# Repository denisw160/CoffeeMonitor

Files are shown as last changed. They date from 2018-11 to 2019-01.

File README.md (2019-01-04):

# CoffeeMonitor
**Retrofit the coffee**

_State: Beta_

This project is a showcase for an IoT application that digitizes our "old" / conventional coffee machine. With the help of basic sensors this project shall show how existing "hardware" can be transformed into the modern digital world.

A presentation about the CoffeeMonitor can be found [here][1] (under construction).

## Why this scenario?

The classic coffee pot is widely used and everyone does not know the problem: if you want to have a coffee, the pot is empty. How good it would be if you knew in advance how much coffee was still available before you went on your way.

## The idea

In order to determine how full the coffee pot is, there are different variants to determine this. A simple variant is to weigh the coffee pot. There are already a number of sensors that can be connected directly.
If you know the empty and full weight, you can easily estimate the degree of filling of the coffee pot.
In addition, I wanted to know how often the coffee pot was refilled. Since the coffee pot has to be removed from the weighing plate, I used a distance sensor that monitors the occupancy of the plate. With the sensor one can count the change of the allocation and/or refilling so. 
Now the data from the sensors must be processed and made available to the user. For this I use a Raspberry Pi 3, which connects the necessary software and hardware components. The sensors are connected to the GPIO ports. The status of the coffee pot is then published via a web application. 

## The solution

All sensors are connected to the GPIO ports. This looks like this, for example. 

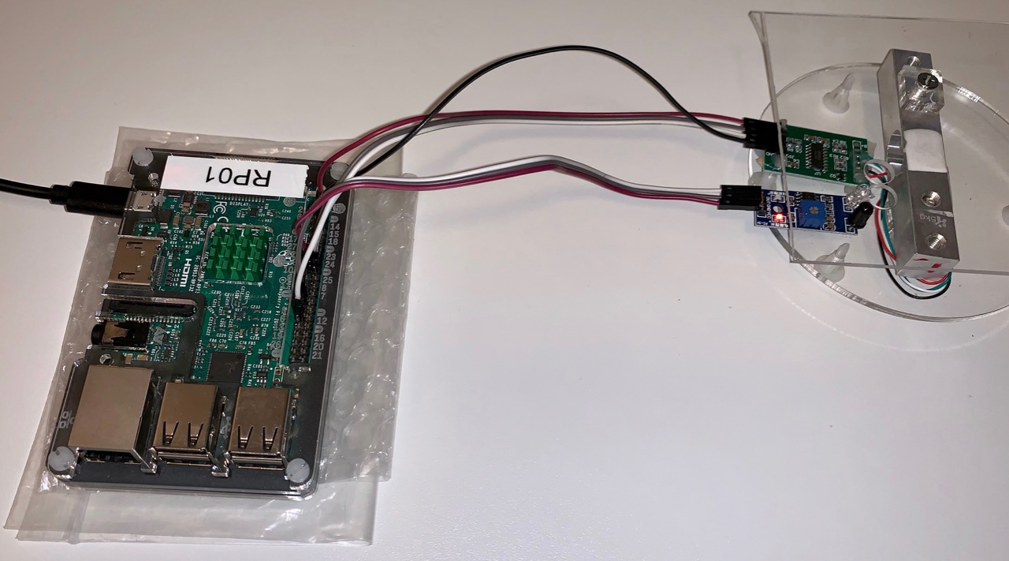
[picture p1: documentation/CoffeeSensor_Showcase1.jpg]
Raspberry complete


A weight cell with a HX711 is used as weighing sensor. In order for the IR distance sensor (FC-51) to work properly, the plate must be provided with two holes for weighing.

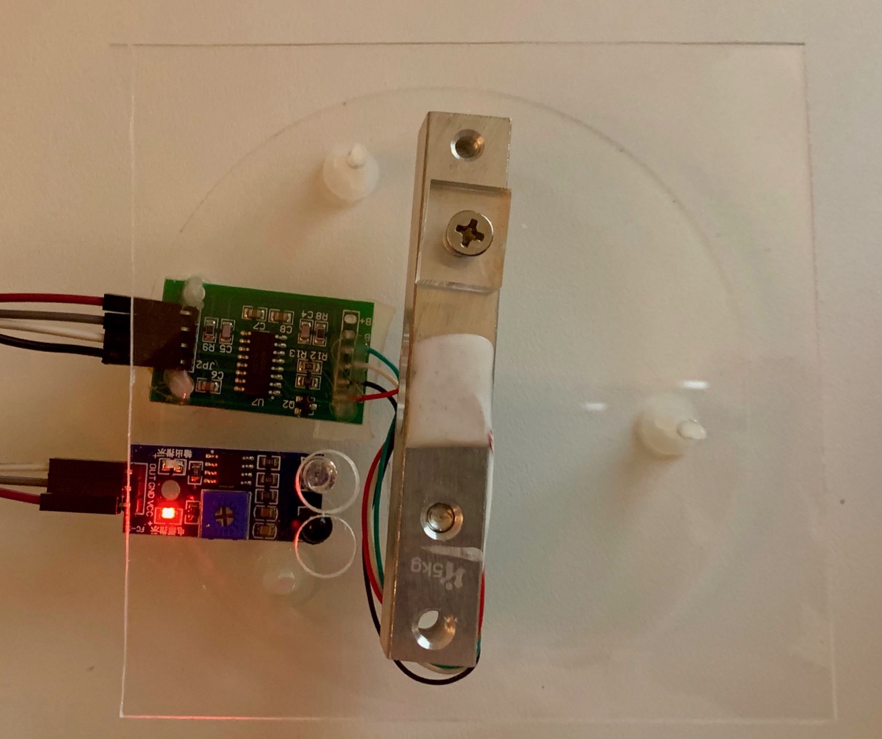
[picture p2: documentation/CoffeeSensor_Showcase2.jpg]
Sensors of the CoffeeMonitor


The structure and connection to the Raspberry Pi is as follows

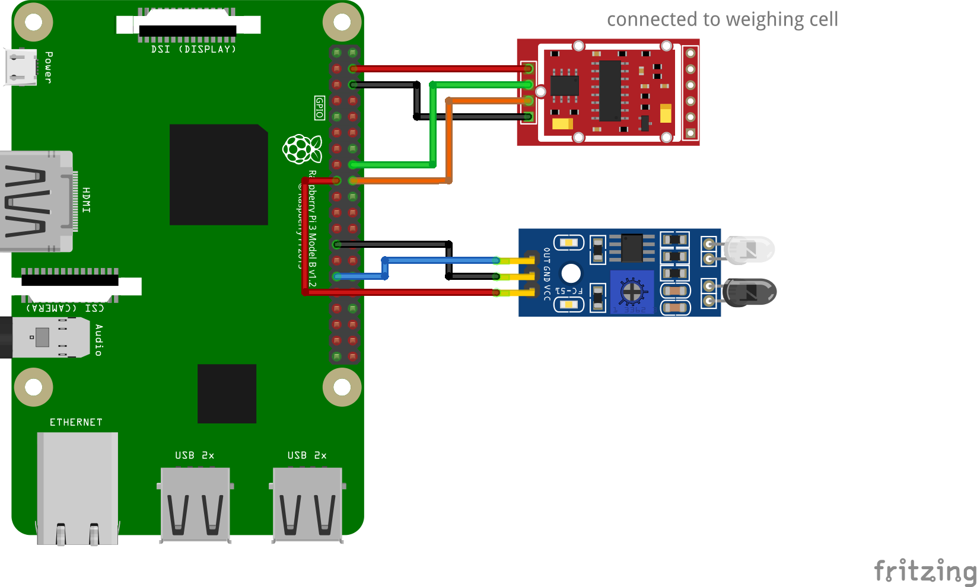
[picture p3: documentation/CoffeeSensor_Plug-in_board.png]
Plug-in board


The details of the electrical connection can be found in the [Fritzing file][2].

## The architecture

The software consists of three modules:
- [CoffeeSensor][3]: a Python script that reads the data from the sensors and transmits it to an MQTT broker.
- [CoffeeService][4]: a Spring Boot application (Java) that receives messages from the MQTT Broker and stores them in a MongoDB. The application also provides a REST API to retrieve the data from the MongoDB.
- [CoffeeApp][5]: An angular application that retrieves and displays the data via the REST service. 

Optional you can use a ESP8266 as CoffeeSensor. You found the source and the wiring diagram in [CoffeeSensor_ESP][6].

### The prerequisites

The following software components are required on the Raspberry:
- Mosquito MQTT-Broker
- MongoDB from 2.6
- Python 2.x and PIP
- Java 1.8
- Node.js

The installation can be carried out using the setup scripts.

## Features of the application

Display how full the coffee pot is

**Full**
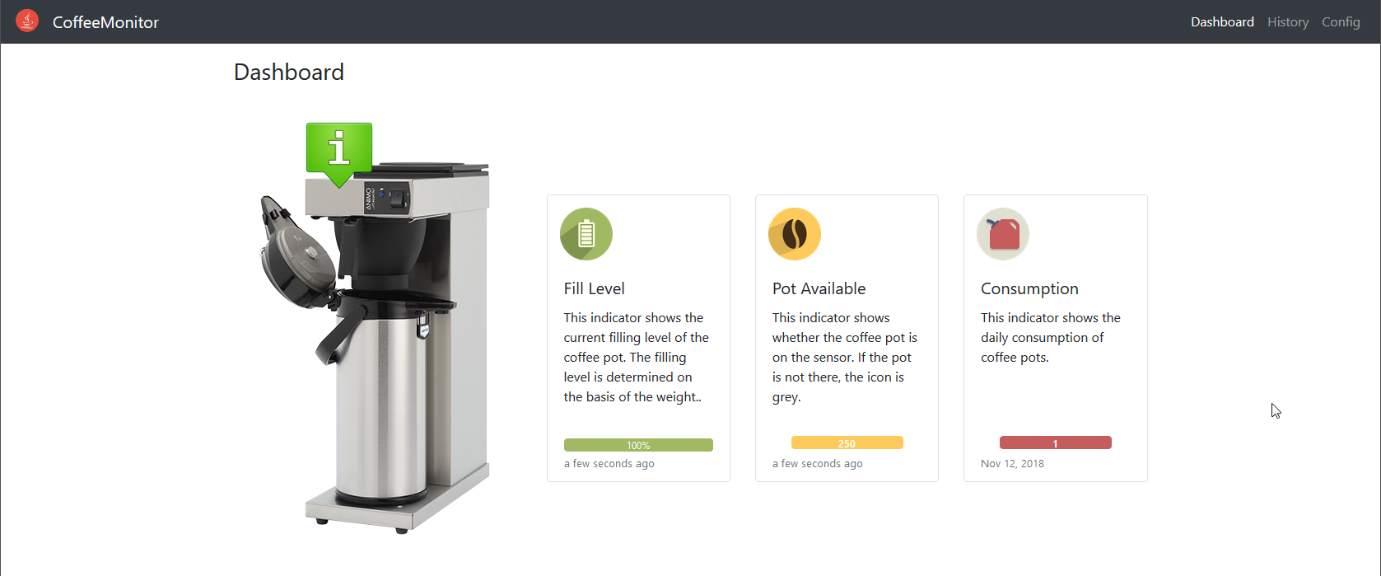
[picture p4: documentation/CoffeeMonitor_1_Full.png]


**Some coffee taken**
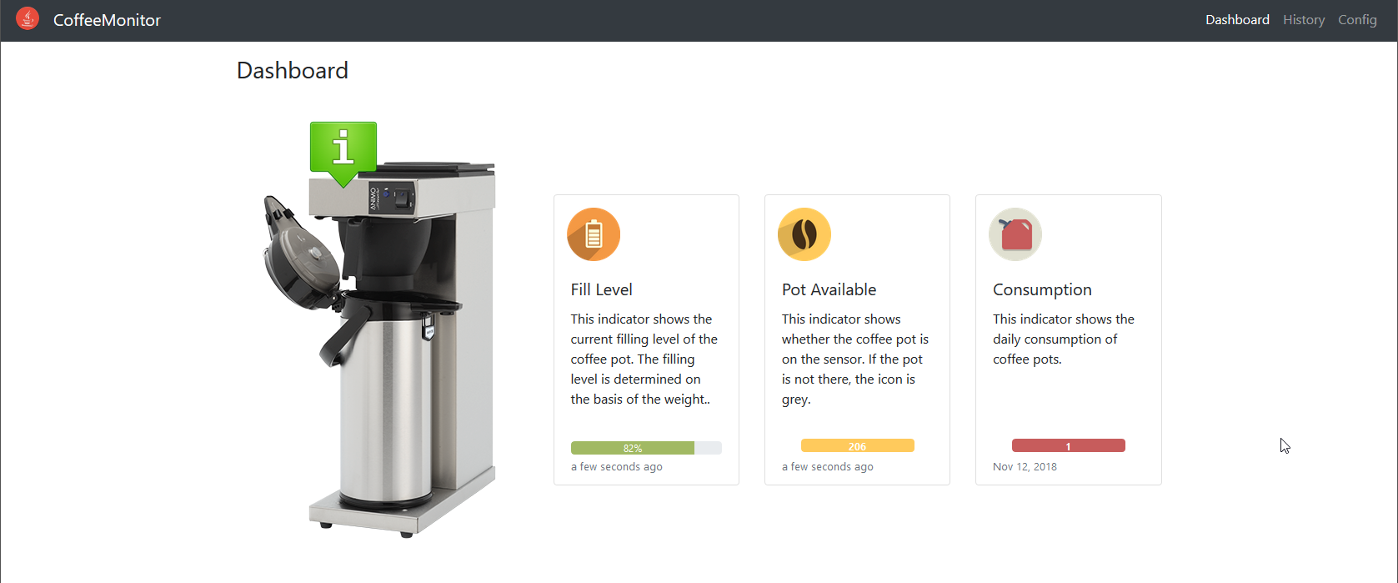
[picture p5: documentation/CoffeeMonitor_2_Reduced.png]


**Almost empty**
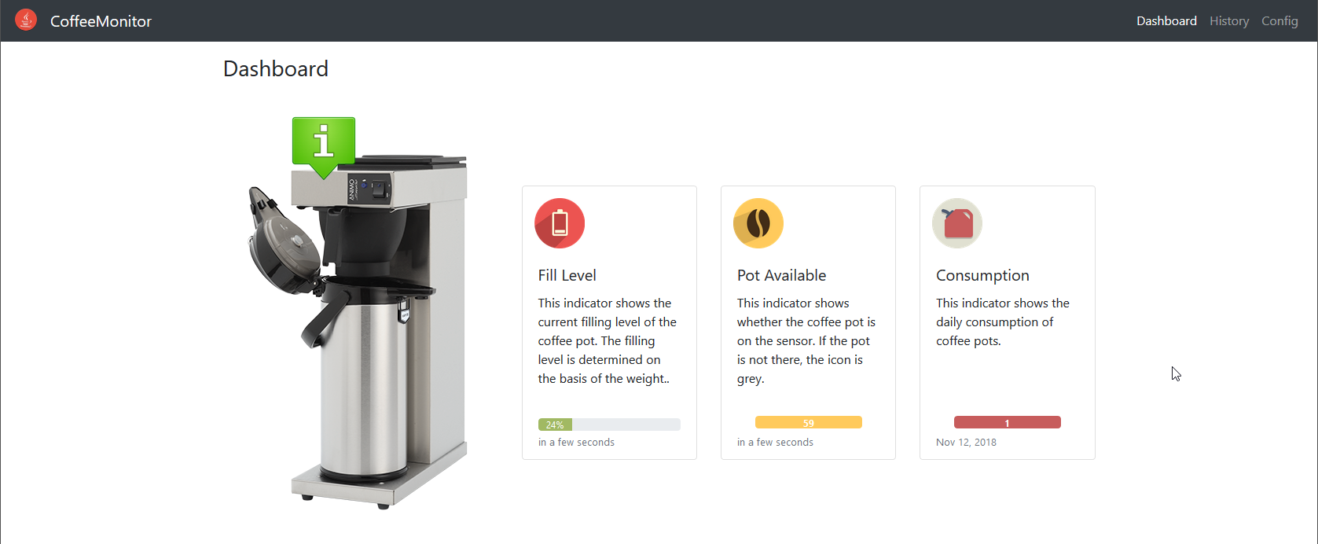
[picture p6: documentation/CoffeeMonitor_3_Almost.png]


**Empty**
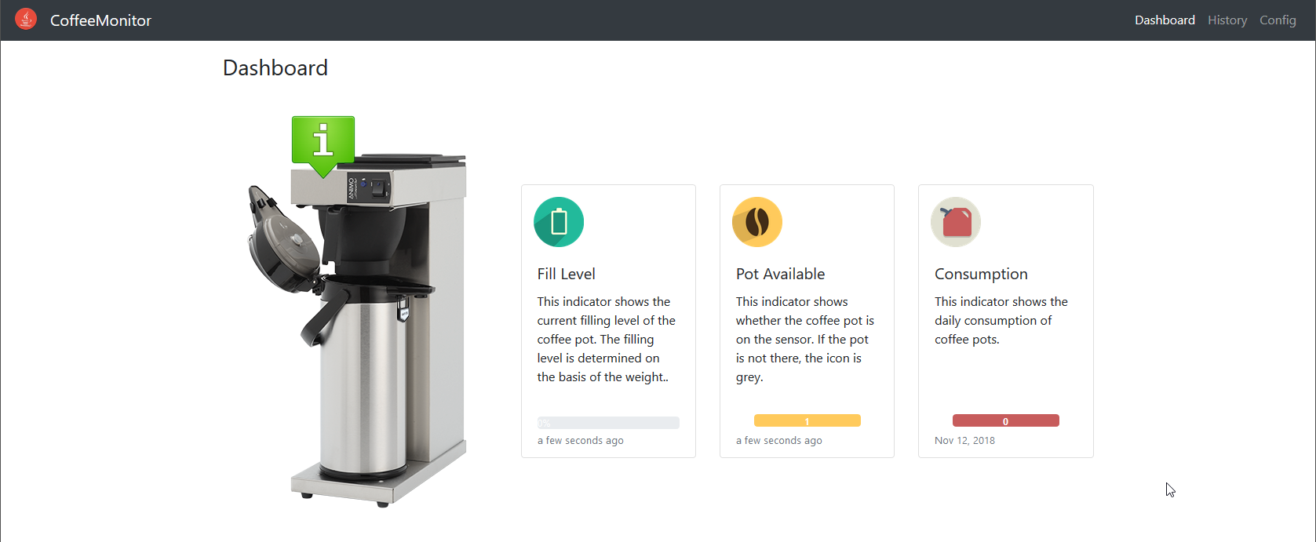
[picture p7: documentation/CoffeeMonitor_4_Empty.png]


If the application detects that no more data is being transferred, this is displayed.
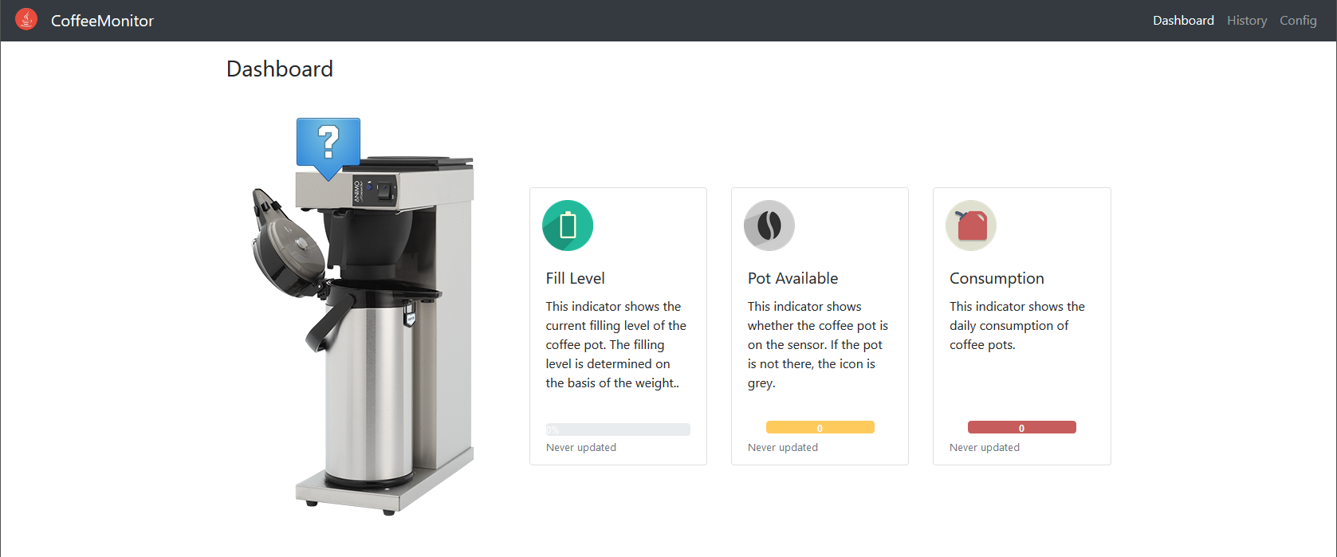
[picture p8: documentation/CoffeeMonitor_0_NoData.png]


The application can be used both on the desktop and on mobile devices.
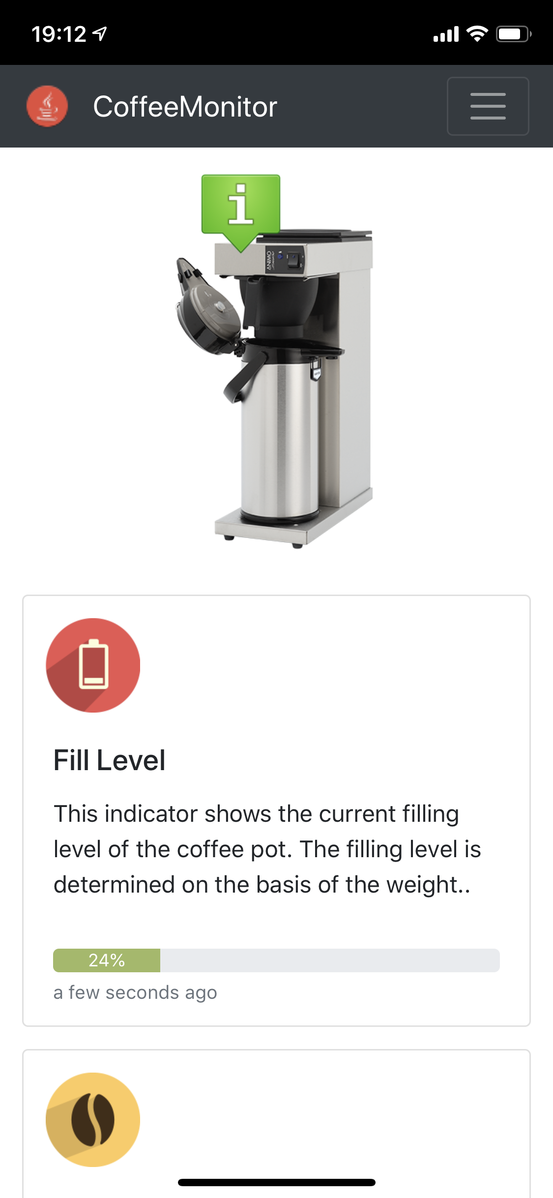
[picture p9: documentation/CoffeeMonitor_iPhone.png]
 <!-- .element height="50%" width="50%" -->

The configuration of the weights (filling and empty weight) can be set directly in the web application. 
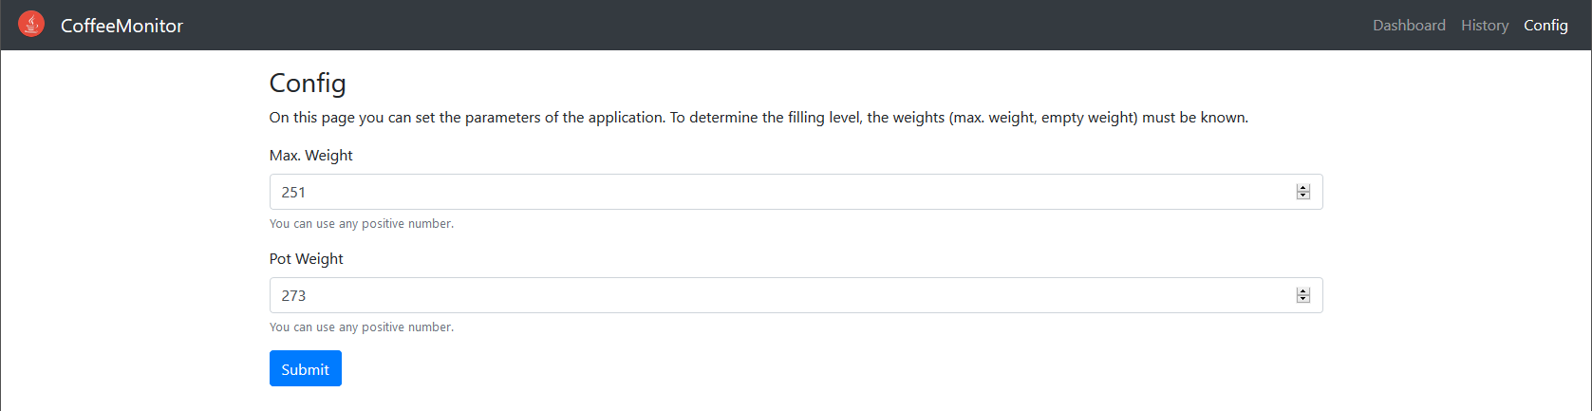
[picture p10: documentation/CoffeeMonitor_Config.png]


The progression of the filling level as well as the refilling can be tracked in the history.
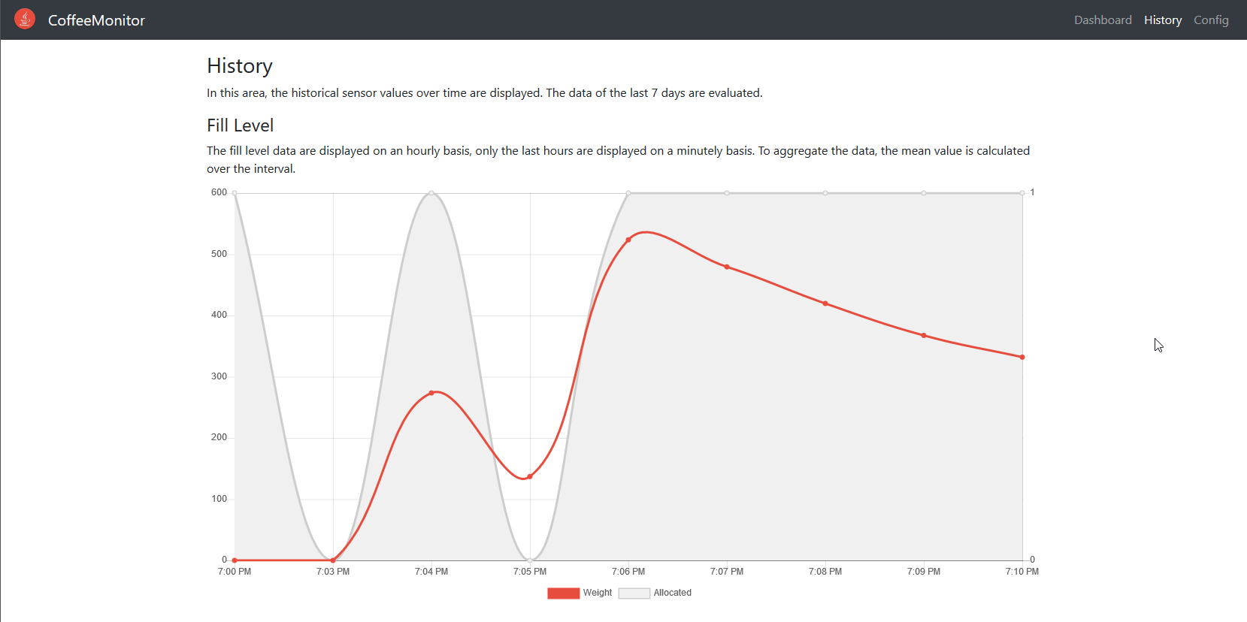
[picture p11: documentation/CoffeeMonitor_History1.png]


[1]:	documentation/CoffeeMonitor.pdf "Presentation of the CoffeeMonitor"
[2]:	documentation/CoffeeSensor.fzz
[3]:	coffeesensor
[4]:	coffeeservice
[5]:	coffeeapp
[5]:	coffeesensor_esp

[image-1]:	documentation/CoffeeSensor_Showcase1.jpg "Showcase 1"
[image-2]:	documentation/CoffeeSensor_Showcase2.jpg "Sensors"
[image-3]:	documentation/CoffeeSensor_Plug-in_board.png "Plug-in board"
[image-4]:	documentation/CoffeeMonitor_1_Full.png
[image-5]:	documentation/CoffeeMonitor_2_Reduced.png
[image-6]:	documentation/CoffeeMonitor_3_Almost.png
[image-7]:	documentation/CoffeeMonitor_4_Empty.png
[image-8]:	documentation/CoffeeMonitor_0_NoData.png
[image-9]:	documentation/CoffeeMonitor_iPhone.png
[image-10]:	documentation/CoffeeMonitor_Config.png
[image-11]:	documentation/CoffeeMonitor_History1.png

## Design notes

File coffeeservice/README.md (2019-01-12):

## CoffeeService

### Description
This module provides the backend for the system. The Spring Boot application handles the incoming mqtt messages from the
sensor and stores the data in a MongoDB. With rest services the data can be query from the clients. 
This module is written in Java 1.8. For Spring Boot the version 2.1.0.RELEASE is used.

### Scripts
To install the required components, simply run the setup script. The installation requires SUDO rights.

    bash>setup.sh

To install the service, simply run the install script. The installation requires SUDO rights.

    bash>install.sh

To uninstall the service, simply run the uninstall script. The installation requires SUDO rights.

    bash>uninstall.sh

The start script can be used to start the server on the local console.

    bash>start.sh

The run script can be used to build and start the server on the local console.

    bash>run.sh

For clean and building the service the following scripts can be used.

    bash>clean.sh
    bash>build.sh

To start the Docker build, execute this script

    bash>docker_build.sh

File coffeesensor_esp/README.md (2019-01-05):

## CoffeeSensor for ESP8266

### Description
This module can be installed on a ESP8266 / NodeMCU. It starts the monitoring of the sensors (GPIO) and transmits the values to the MQTT broker. 
This module is written in the Arduino IDE.

The data is send every 15 seconds. If you want another update interval, please change the variable INTERVAL.

The connection of the hardware (sensors) can be found [here][1].
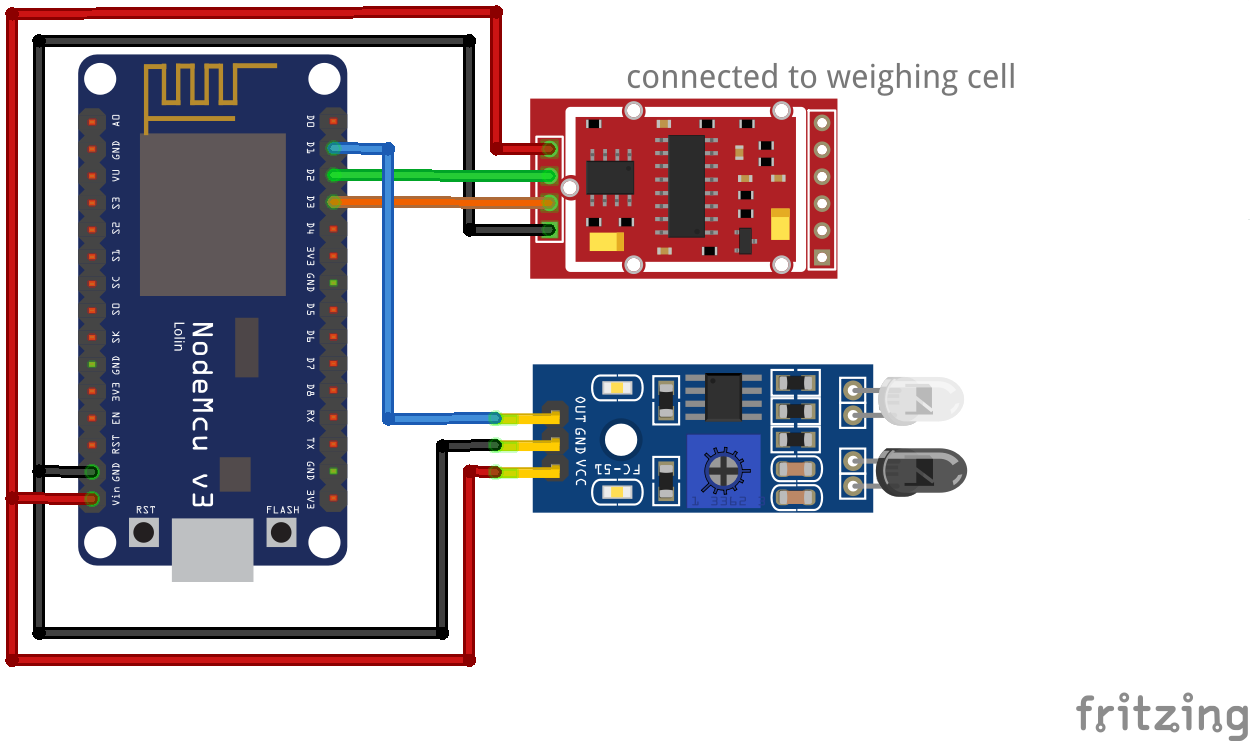
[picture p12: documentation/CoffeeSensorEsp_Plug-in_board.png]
Plug-in board for ESP8266


You need the following libraries in your Arduino IDE.

- HX711\_ADC by Olav Kallhovd ([https://github.com/olkal/HX711\_ADC][2])
- ArduinoMqtt by Oleg Kovalenko ([https://github.com/monstrenyatko/ArduinoMqtt][3])
- WiFiManager by tzapu ([https://github.com/tzapu/WiFiManager][4])

### Install
For install the software, open the file CoffeeSensorEsp.ino in your Arduino IDE and flash the ESP8266.

### Setup
On the first start of the NodeMCU it try to connect to a WiFi. If no WiFi parameter set, the NodeMCU stops and create and open WiFi network (AutoConnectAP). 
Please connect to this network and update your WiFi credentials and MQTT server. Then the NodeMCU restarts and automatically connect to your WiFi network.

You can canfigure the following MQTT parameter:

- MQTT Server: IP or hostname of your MQTT server
- MQTT Port: Your port of your server (default: 1883 or SSL: 8883)
- MQTT Topic: The topic for the sensor data, you must have write access for this topic
- MQTT User: Your username for the the server
- MQTT Password: The password for the user
- MQTT SSL: 1 for use SSL for the connection, 0 disable SSL

The MQTT ID of the client is the hostname of the ESP8266.

### Debug
In the serial monitor you can see the messages of the module.

[1]:	../documentation/CoffeeSensorEsp.fzz
[2]:	https://github.com/olkal/HX711_ADC "GitHub for HX711"
[3]:    https://github.com/monstrenyatko/ArduinoMqtt "GitHub for ArdunioMqtt"
[4]:    https://github.com/tzapu/WiFiManager "GitHub for WiFiManager"

[image-1]:	../documentation/CoffeeSensorEsp_Plug-in_board.png "Plug-in board for ESP8266"

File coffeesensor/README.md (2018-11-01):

## CoffeeSensor

### Description
This module starts the monitoring of the sensors (GPIO) and transmits the values to the MQTT broker. 
This module is written in Python 2.x. For the connection to the mqtt broker the python lib from paho.mqtt is used.

The connection of the hardware (sensors) can be found in the main folder under /documentation.

### Scripts
To install the required components, simply run the setup script. The installation requires SUDO rights.

    bash>setup.sh

To install the service, simply run the install script. The installation requires SUDO rights.

    bash>install.sh

To uninstall the service, simply run the uninstall script. The installation requires SUDO rights.

    bash>uninstall.sh

The start script can be used to start the server on the local console.

    bash>start.sh

The test script can be used for testing without hardware. It generates random values and transfers them.

    bash>test.sh

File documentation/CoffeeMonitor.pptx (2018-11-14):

## CoffeeMonitor

“Retrofit the coffee"

## The challenge

## The solution

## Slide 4

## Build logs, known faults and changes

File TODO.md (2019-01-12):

## Tasks and open points

- Design of the scale casing for determining the weight of the coffee pot (protected against moisture and excessive weights / pressure on the coffee pot)
- Add reset button for ESP8266
- Add JWT for securing the connection and active CSRF for POST requests
- Implement cleanup job for old data

## Ideas and next steps

- Native app for iOS and Android
- Indication when the coffee pot was last refilled
- Add RFID or NFC scanner for identify the coffee users / display the last users
- Adding Machine Learning (ML) for detection of invalid sensor data

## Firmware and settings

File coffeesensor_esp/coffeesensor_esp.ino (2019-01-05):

// External libraries
#include <FS.h> // this needs to be first, or it all crashes and burns...
#include <ESP8266WiFi.h>
#include <DNSServer.h>
#include <WiFiManager.h>
#include <ESP8266WebServer.h>
#include <HX711_ADC.h>
#include <MqttClient.h>
#include <ArduinoJson.h>

// Interval for update
#define INTERVAL 15000

// Show debug messages in serial
#define DEBUG true

// Port on NodeMCU (D1) for the allocation sensor
#define ALLOCATION_SENSOR D1

// Ports on NodeMCU for the weight sensor - SCK (D2) + DT (D3)
#define WEIGHT_SCK D2
#define WEIGHT_DT D3


// Control Parameter
// define your default values here, if there are different values in config.json, they are overwritten.
char mqttServer[50];
char mqttPort[6] = "1883";
char mqttTopic[50] = "me/wirries/coffeesensor";
char mqttSsl[2] = "0";
char mqttUsername[50];
char mqttPassword[50];


// HX711 - constructor (dout pin, sck pin):
HX711_ADC LoadCell(WEIGHT_DT, WEIGHT_SCK);

// MqttClient
MqttClient *mqtt = NULL;
WiFiClient network;
WiFiClientSecure netsecure;
String mqttId;
int mPort;
bool mSsl;
bool mSecure;

// Heartbeat status
boolean led = false;

// Time mills for update
long t;

// Flag for saving data
bool shouldSaveConfig = false;


//
// MqttSystem implementation
class MqttSystem: public MqttClient::System {
  public:

    unsigned long millis() const {
      return ::millis();
    }

    void yield(void) {
      ::yield();
    }
};


//
// Initialize and setup
void setup() {
  // Initialize Debug-Console
  Serial.begin(115200);
  Serial.println("Booting ...");


  // Initialize the pins as in-/output
  Serial.println("Initialize pins ...");
  pinMode(LED_BUILTIN, OUTPUT);
  pinMode(ALLOCATION_SENSOR, INPUT);


  // Handle configuration
  // Clean filesystem - remove old config
  //SPIFFS.format();

  // Read configuration from FS json
  Serial.println("Mounting file system ...");
  if (SPIFFS.begin()) {
    if (SPIFFS.exists("/config.json")) {
      // File exists, reading and loading
      Serial.println("Loading config from file ...");
      File configFile = SPIFFS.open("/config.json", "r");
      if (configFile) {
        size_t size = configFile.size();
        std::unique_ptr<char[]> buf(new char[size]);
        configFile.readBytes(buf.get(), size);
        DynamicJsonBuffer jsonBuffer;
        JsonObject& json = jsonBuffer.parseObject(buf.get());

        if (DEBUG) json.printTo(Serial);
        if (json.success()) {
          if (DEBUG) Serial.println("\nConfig parsed");

          strcpy(mqttServer, json["mqtt_server"]);
          strcpy(mqttPort, json["mqtt_port"]);
          strcpy(mqttTopic, json["mqtt_topic"]);
          strcpy(mqttSsl, json["mqtt_ssl"]);
          strcpy(mqttUsername, json["mqtt_username"]);
          strcpy(mqttPassword, json["mqtt_password"]);

          Serial.println("Config loaded");
        } else {
          Serial.println("Failed to load config");
        }
        configFile.close();
      }
    }
  } else {
    Serial.println("Failed to mount file system");
  }

  // The extra parameters to be configured (can be either global or just in the setup)
  // After connecting, parameter.getValue() will get you the configured value
  // id/name placeholder/prompt default length
  WiFiManagerParameter customMqttServer("server", "mqtt server", mqttServer, 50);
  WiFiManagerParameter customMqttPort("port", "mqtt port [int]", mqttPort, 6);
  WiFiManagerParameter customMqttTopic("topic", "mqtt topic", mqttTopic, 50);
  WiFiManagerParameter customMqttSsl("ssl", "mqtt ssl - 0 or 1", mqttSsl, 2);
  WiFiManagerParameter customMqttUsername("username", "mqtt username - blank for disable", mqttUsername, 50);
  WiFiManagerParameter customMqttPassword("password", "mqtt password - blank for disable", mqttPassword, 50);

  // WiFiManager - local intialization.
  WiFiManager wifiManager;
  // reset saved settings - for deleting the settings
  //wifiManager.resetSettings();

  // set config save notify callback
  wifiManager.setSaveConfigCallback(saveConfigCallback);

  // add all parameters
  wifiManager.addParameter(&customMqttServer);
  wifiManager.addParameter(&customMqttPort);
  wifiManager.addParameter(&customMqttTopic);
  wifiManager.addParameter(&customMqttSsl);
  wifiManager.addParameter(&customMqttUsername);
  wifiManager.addParameter(&customMqttPassword);

  // fetches ssid and pass from eeprom and tries to connect
  // if it does not connect it starts an access point
  // and goes into a blocking loop awaiting configuration
  wifiManager.autoConnect("AutoConnectAP");

  Serial.print("Connecting to WiFi .");
  while (WiFi.status() != WL_CONNECTED) {
    delay(500);
    Serial.print(".");
  }
  Serial.println(" connected!");
  Serial.println("Hostname: " + WiFi.hostname());
  Serial.println("IP: " + WiFi.localIP().toString());

  // Setup hostname as MQTT_ID
  mqttId = "CoffeeSensor_" + WiFi.hostname();

  // Setup / update parameter
  strcpy(mqttServer, customMqttServer.getValue());
  strcpy(mqttPort, customMqttPort.getValue());
  strcpy(mqttTopic, customMqttTopic.getValue());
  strcpy(mqttSsl, customMqttSsl.getValue());
  strcpy(mqttUsername, customMqttUsername.getValue());
  strcpy(mqttPassword, customMqttPassword.getValue());

  // Save the custom parameters to file system
  if (shouldSaveConfig) {
    Serial.println("Saving config ...");
    DynamicJsonBuffer jsonBuffer;
    JsonObject& json = jsonBuffer.createObject();
    json["mqtt_server"] = mqttServer;
    json["mqtt_port"] = mqttPort;
    json["mqtt_topic"] = mqttTopic;
    json["mqtt_ssl"] = mqttSsl;
    json["mqtt_username"] = mqttUsername;
    json["mqtt_password"] = mqttPassword;

    File configFile = SPIFFS.open("/config.json", "w");
    if (!configFile) {
      Serial.println("Failed to open config file for writing");
    }

    if (DEBUG) json.printTo(Serial);
    json.printTo(configFile);
    configFile.close();
    Serial.println("\nConfig saved");
  }

  // Setup port
  mPort = String(mqttPort).toInt();
  mSsl = String(mqttSsl) == "1";
  mSecure = String(mqttUsername).length() > 0;


  // Initialize MqttClient
  Serial.println("Initialize MQTT client ...");
  MqttClient::System *mqttSystem = new MqttSystem();
  MqttClient::Logger *mqttLogger = new MqttClient::LoggerImpl<HardwareSerial>(Serial);
  MqttClient::Network *mqttNetwork = mSsl ?  new MqttClient::NetworkClientImpl<WiFiClient>(netsecure, *mqttSystem) : new MqttClient::NetworkClientImpl<WiFiClient>(network, *mqttSystem);
  MqttClient::Buffer *mqttSendBuffer = new MqttClient::ArrayBuffer<128>();
  MqttClient::Buffer *mqttRecvBuffer = new MqttClient::ArrayBuffer<128>();
  MqttClient::MessageHandlers *mqttMessageHandlers = new MqttClient::MessageHandlersImpl<2>();
  MqttClient::Options mqttOptions;
  mqttOptions.commandTimeoutMs = 10000;
  mqtt = new MqttClient(mqttOptions, *mqttLogger, *mqttSystem, *mqttNetwork, *mqttSendBuffer, *mqttRecvBuffer, *mqttMessageHandlers);
  Serial.println("MQTT client is ready");


  // Initialize weight sensor
  Serial.println("Initialize weight sensor ...");

  float calValue = 1;
  // calibration value
  // How to find this value
  // First you need a comparison object whose weight you know. E.g. a water bottle can be used well.
  // The weight should have an average value of the maximum of the load cell.
  // First you have to comment out the line with the reference value. Then start the program and follow
  // the outputs. Place the object. The displayed values can be positive or negative.
  // In this example, values around -402000 were displayed at 1kg (=1000g).
  // So this reference value is: -402000 / 1000 = -402.
  calValue = 385.92;

  LoadCell.begin();
  long stabilisingtime = 2000; // tare preciscion can be improved by adding a few seconds of stabilising time
  LoadCell.start(stabilisingtime);

  if (LoadCell.getTareTimeoutFlag()) {
    Serial.println("Tare timeout, check MCU>HX711 wiring and pin designations");
  } else {
    LoadCell.setCalFactor(calValue); // set calibration value (float)
    Serial.println("Weight sensor is ready");
  }

  Serial.println("Setup completed.");
}

//
// Run system loop
void loop() {
  // update() should be called at least as often as HX711 sample rate; >10Hz@10SPS, >80Hz@80SPS
  // use of delay in sketch will reduce effective sample rate (be carefull with use of delay() in the loop)
  LoadCell.update();

  // Update and send data in interval
  if (millis() > t + INTERVAL) {
    boolean allocation = readAllocation();
    float weight = readWeight();
    sendMqttMessage(allocation, weight);

    heartbeat();
    t = millis();
  }
}

//
// Read the allocation from the sensor and
// return the value as boolean.
// - TRUE=allocated
// - FALSE=free
boolean readAllocation() {
  boolean allocation = digitalRead(ALLOCATION_SENSOR) == 0;

  // Debug message
  if (DEBUG) {
    Serial.print("Allocation is: ");
    if (allocation) {
      Serial.println("allocated");
    } else {
      Serial.println("free");
    }
  }

  return allocation;
}

//
// Read the weight from the sensor and
// return the value.
float readWeight() {
  float weight = LoadCell.getData();

  // Debug message
  if (DEBUG) {
    Serial.print("Weight is: ");
    Serial.println(weight);
  }

  return weight;
}

//
// Convert the sensor values to a JSON message
// and send the message to the MQTT broker.
void sendMqttMessage(boolean allocation, float weight) {
  // Check connection status
  if (!mqtt->isConnected()) {
    if (mSsl) {
      netsecure.stop(); // Close connection if exists
      Serial.println("Reconnecting to MQTT server (secure) ...");
      netsecure.connect(mqttServer, mPort); // Re-establish TCP connection with MQTT broker (secure)
      if (!netsecure.connected()) {
        Serial.println("Can't establish the TCP connection");
      }
    } else {
      network.stop(); // Close connection if exists
      Serial.println("Reconnecting to MQTT server ...");
      network.connect(mqttServer, mPort); // Re-establish TCP connection with MQTT broker
      if (!network.connected()) {
        Serial.println("Can't establish the TCP connection");
      }
    }

    // Start new MQTT connection
    MqttClient::ConnectResult connectResult;
    {
      // Connect
      MQTTPacket_connectData options = MQTTPacket_connectData_initializer;
      options.MQTTVersion = 4;
      if (mSecure) {
        Serial.println("Using login for mqtt  ...");
        options.username.cstring = (char*)mqttUsername;
        options.password.cstring = (char*)mqttPassword;
      }
      options.clientID.cstring = (char*)mqttId.c_str();
      options.cleansession = true;
      options.keepAliveInterval = 45; // 45 seconds
      MqttClient::Error::type rc = mqtt->connect(options, connectResult);
      if (rc != MqttClient::Error::SUCCESS) {
        Serial.print("Connection error: ");
        Serial.println(rc);
        return;
      }
    }
  } else {
    {
      // Sending MQTT message
      // Original structure: {"timestamp": "2019-01-04T10:54:49.517000", "allocated": true, "weight": 1.0406128215270019}
      // ESP8266 short structure : {"allocated": true, "weight": 1.0406128215270019}
      // timestamp will added by the service
      const String a = allocation ? "true" : "false";
      const String w = String(weight);
      const String m = "{\"allocated\": " + a + ", \"weight\": " + w + "}";
      const char* buf = (char*)m.c_str();
      MqttClient::Message message;
      message.qos = MqttClient::QOS0;
      message.retained = false;
      message.dup = false;
      message.payload = (void*) buf;
      message.payloadLen = strlen(buf);
      mqtt->publish(mqttTopic, message);

      if (DEBUG) {
        Serial.print("MQTT message send: ");
        Serial.println(buf);
      }
    }
  }
}

//
// Toogle the LED and write an message to serial.
void heartbeat() {
  if (led) {
    digitalWrite(LED_BUILTIN, LOW);
    if (!DEBUG) Serial.print("*");
    led = false;
  } else {
    digitalWrite(LED_BUILTIN, HIGH);
    if (!DEBUG) Serial.print("-");
    led = true;
  }
}

// callback notifying us of the need to save config
void saveConfigCallback () {
  if (DEBUG) Serial.println("Should save config");
  shouldSaveConfig = true;
}

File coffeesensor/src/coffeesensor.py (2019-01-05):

import argparse
import datetime
import json
import signal
import socket
import ssl
import time

import RPi.GPIO as GPIO
import paho.mqtt.client as MQTT

from hx711 import HX711

#
# This scripts starts the service. The service reads the values (weight, allocated) from the hardware.
# The values are send backend via mqtt.
# For transmission a mqtt broker is used. The format of the data is json:
# {"timestamp":"2012-04-23T18:25:43.511Z", "weight":[double], "allocated":[boolean]}
#
# The mqtt topic "me/wirries/coffeesensor" is used.
#
# The circuit diagram can be found in the folder documentation.
#
#
# require modules
#  - paho-mqtt (pip)
#  - numpy (pip)
#  - python-dev + python-rpi.gpio (apt)
#    or for development fakeRPiGPIO (pip)
#

# Defaults

MQTT_HOST = "localhost"
MQTT_PORT = 1883
MQTT_TOPIC = "me/wirries/coffeesensor"
MQTT_KEEPALIVE_INTERVAL = 45
INTERVAL = 15

# Using GPIO numbers
ALLOCATED_SENSOR = 5  # GPIO 05 / PIN 29
WEIGHT_SENSOR_DT = 24  # GPIO 24 / PIN 18
WEIGHT_SENSOR_SCK = 23  # GPIO 23 / PIN 16


# Classes

class GracefulKiller:
    kill_now = False

    def __init__(self):
        signal.signal(signal.SIGINT, self.exit_gracefully)
        signal.signal(signal.SIGTERM, self.exit_gracefully)

    def exit_gracefully(self, signum, frame):
        self.kill_now = True


# Functions

# Define on_publish event function
def on_publish(client, userdata, mid):
    print "Message published"


# Define isNotBlank function for testing, if a String is blank
def is_not_blank(s):
    if s and s.strip():
        return True
    return False


# Starting server
ap = argparse.ArgumentParser()
ap.add_argument("-s", "--server", required=False, help="server / default: " + MQTT_HOST, default=MQTT_HOST)
ap.add_argument("-p", "--port", required=False, help="port / default: " + str(MQTT_PORT), default=str(MQTT_PORT))
ap.add_argument("-c", "--ca", required=False, help="path to ca file (full chain) to verify the SSL connection")
ap.add_argument("-t", "--topic", required=False, help="topic for publish / default: " + MQTT_TOPIC, default=MQTT_TOPIC)
ap.add_argument("-u", "--user", required=False, help="username for login")
ap.add_argument("-w", "--password", required=False, help="password for user")
args = vars(ap.parse_args())

host = args["server"]
port = args["port"]
ca = args["ca"]
topic = args["topic"]
user = args["user"]
password = args["password"]

print "CoffeeSensor started - for stopping please press CRTL-c"
print " - MQTT-Broker:", MQTT_HOST
print " - MQTT-Port:", MQTT_PORT
print " - MQTT-Keepalive:", MQTT_KEEPALIVE_INTERVAL
print " - MQTT-Topic:", MQTT_TOPIC

loginEnabled = is_not_blank(user) and is_not_blank(password)
if loginEnabled:
    print " - use login for connection with user:", user

sslEnabled = is_not_blank(ca)
if sslEnabled:
    print " - use ca file for SSL connection:", ca

# Initiate MQTT Client
mqttc = MQTT.Client(client_id="CoffeeSensor_" + socket.gethostname())
# Register publish callback function
mqttc.on_publish = on_publish

# Setup login for connection
if loginEnabled:
    mqttc.username_pw_set(user, password)

# Setup SSL connection
if sslEnabled:
    mqttc.tls_set(ca, tls_version=ssl.PROTOCOL_TLSv1_2)
    mqttc.tls_insecure_set(False)

# Connect with MQTT Broker
mqttc.connect(host, port, MQTT_KEEPALIVE_INTERVAL)

# Setup GPIO layout
GPIO.setmode(GPIO.BCM)
GPIO.setup(ALLOCATED_SENSOR, GPIO.IN)  # as input

# Setup weight sensor
hx = HX711(WEIGHT_SENSOR_DT, WEIGHT_SENSOR_SCK)
hx.set_reading_format("LSB", "MSB")

# Reference value for the weight sensor.
hx.set_reference_unit(-392)
# How to find this value
# First you need a comparison object whose weight you know. E.g. a water bottle can be used well.
# The weight should have an average value of the maximum of the load cell.
# First you have to comment out the line with the reference value. Then start the program and follow
# the outputs. Place the object. The displayed values can be positive or negative.
# In this example, values around -402000 were displayed at 1kg (=1000g).
# So this reference value is: -402000 / 1000 = -402.

hx.reset()
hx.tare()
print "Weight sensor ready"

# Running server
try:
    killer = GracefulKiller()

    while True:
        # Reading values from sensors
        allocated = GPIO.input(ALLOCATED_SENSOR)
        weight = hx.get_weight(5)
        hx.power_down()
        hx.power_up()

        # Output for debugging
        print "Allocated is ", allocated  # High is free
        print "Weight is ", weight

        if weight < 0:
            weight = 0  # ignore negative values

        timestamp = str(datetime.datetime.now().isoformat())
        msg = json.dumps({"timestamp": timestamp, "weight": weight, "allocated": allocated == 0})
        print "MQTT message: ", msg

        # Publish message to MQTT Broker
        mqttc.publish(topic, msg)

        if killer.kill_now:
            break

        # wait for next update
        time.sleep(INTERVAL)

except KeyboardInterrupt:
    print "Strg-C called"

finally:
    print "CoffeeSensor stopped"
    # Release GPIO ports
    GPIO.cleanup()
    # Disconnect from MQTT_Broker
    mqttc.disconnect()

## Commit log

2018-11-01 Themes for Angular Material
2018-11-01 Modules for Angular Material
2018-11-02 switch to boostrap
2018-11-02 design and sample for history
2018-11-02 Hiding config on smaller devices
2018-11-02 adding new service for sensor data from the last 7 days
2018-11-03 Adding index in SensorData
2018-11-05 Connection sensor and cleanup
2018-11-06 Adding wiring information
    [CoffeeSensor.fzz]
2019-01-03 Adding wiring diagram
    [CoffeeSensorEsp.fzz]
2019-01-05 Change client id, intervall to 15s and move documentation
    [CoffeeSensorEsp.fzz]
2019-01-07 Adding docker support for sensor (only test)
2019-07-19 rename for open in Arduino IDE
